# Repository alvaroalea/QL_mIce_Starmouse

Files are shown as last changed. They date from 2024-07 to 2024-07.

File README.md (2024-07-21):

# QL_mIce_Starmouse
Mouse Interface for sinclair QL, mIce and Starmouse compatible

Reverse Engineered and adapted in 2024 by Alvaro Alea Fernandez

License under: CERN Open Hardware Licence Version 2 - Strongly Reciprocal

https://ohwr.org/cern_ohl_s_v2.txt

My work is only copy the design to Kicad, all (C) are retaing to the original owners.

# Introduction

ICE was a early graphic enviroment for the Sinclair QL, it was distributed in ROM Cartridge format, version 1 use keys, but version 2 incorporate a mouse for manage the enviroment.

This project clone the hardware board that have a socket for a ROM chip with ICE, and the circuit to manage te mouse, This Board has been design to match 1:1 the pictures I found of the original board, so can schematic and board can be usefull to repair the original Cartridge.

Original use a bus-mouse, a early kind of no-smart mouse where the signal of the encoders in X and Y are passed to the host computer, this kind of mouse area also used by BBC, Spectrum, Comodore Amiga, Atari ST and early PC XT, today is almost imposible to got one, so I add a second board, using a raspberry pi pico microcontroller that emulate this kind of mouses with a standard USB mouse. This board can also be used on other computers with the adecuate wiring.

A Spanish Company develop another mouse interface for the QL, Starmouse, this interface emulate key push using the second Joystick port (that is also used for the F1-F5 keys) and got power from the cartridge port. This second board can also allow to emulate this mouse. if you connect the adecuate cable to the joystick port.

A small switch in the board will allow you to select, even on they fly, which mouse emulate.

in the folder case there is a PDF with a sticker and a 3D model to print a case for this interface.

in the folder pizero_mouse_usb you can found the source code and binery (.UF2 file) of the firmware to install on the raspberry pi pico. you should use a "waveshare RP-2024 Zero"

in the folder gerber_to_order you can found .zip files ready to send to the mains PCB manufacturers (this is automatic generated, not checked, you should do by yourself)

# Technical Information

This kind of mouse are not the best option for a moderm, multikasking operating system, there is no driver for the mouses, and the programs itself has to take care of pooling the device constantely to got the movement, for the Ice enviroment the vendor provide a toolkit (library) of routines to make easy the integration, but AFAIK, there where no aditional sofware that allow to use it. In the case of the Starmouse, there is only one program that use it, and there is no companion toolkit to use it.

There is no pointer enviroment driver for neither of the mouses.

# Pictures

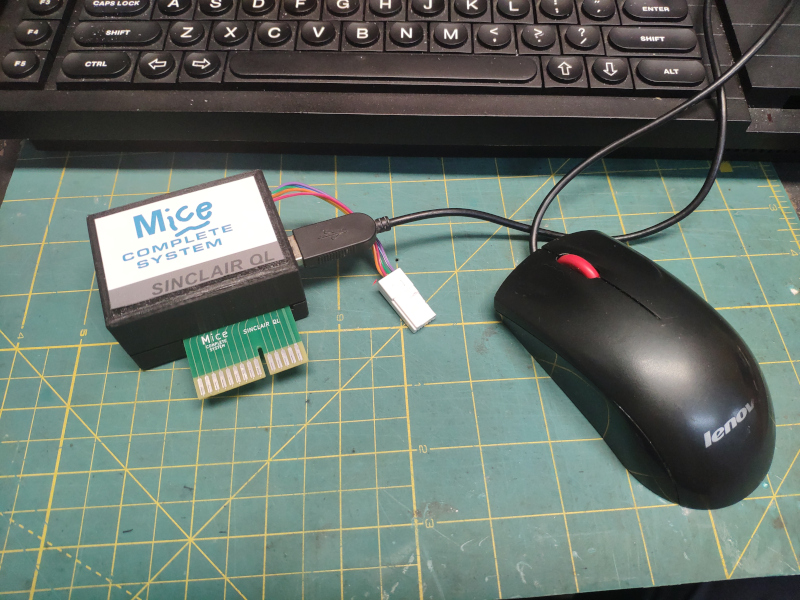
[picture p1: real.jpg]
Real


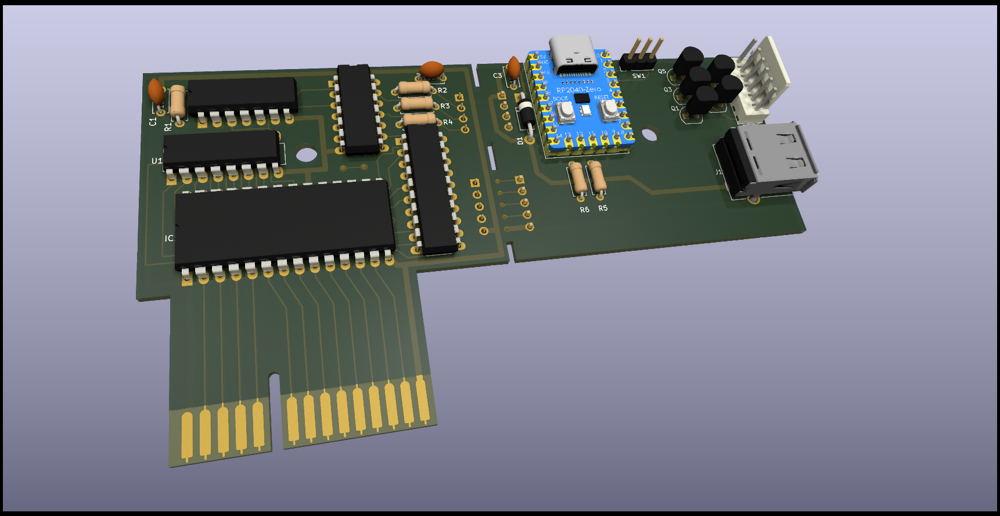
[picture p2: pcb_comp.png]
PCB Componentes Side


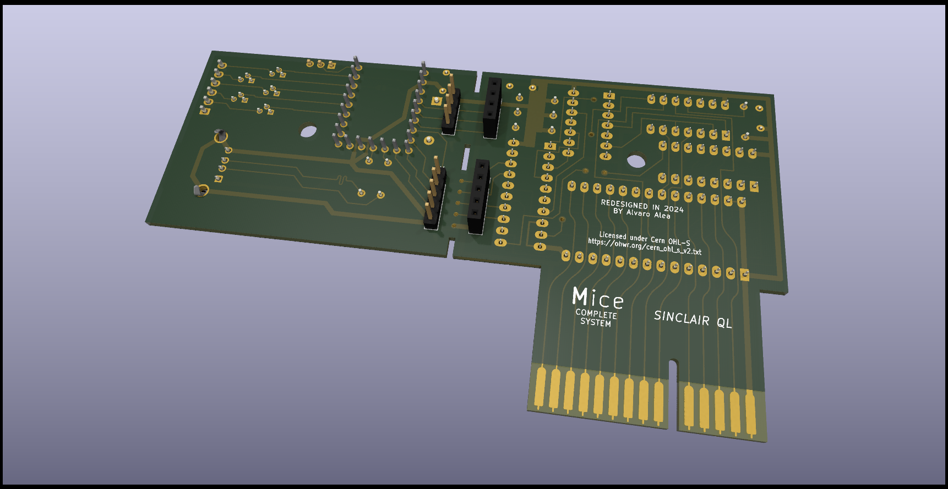
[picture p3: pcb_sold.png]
PCB Solder Side


# Links

https://qlwiki.qlforum.co.uk/doku.php?id=qlwiki:ice

https://qlwiki.qlforum.co.uk/doku.php?id=qlwiki:starmouse

https://sinclairql.speccy.org/articulos/historia/starmouse.htm

https://sinclairql.speccy.org/articulos/hardware/escarabajo.htm

https://www.waveshare.com/rp2040-zero.htm

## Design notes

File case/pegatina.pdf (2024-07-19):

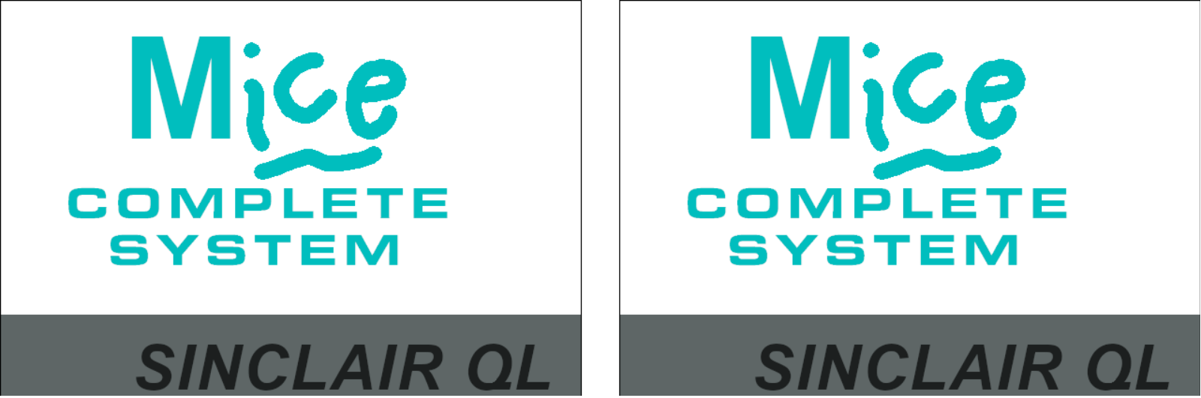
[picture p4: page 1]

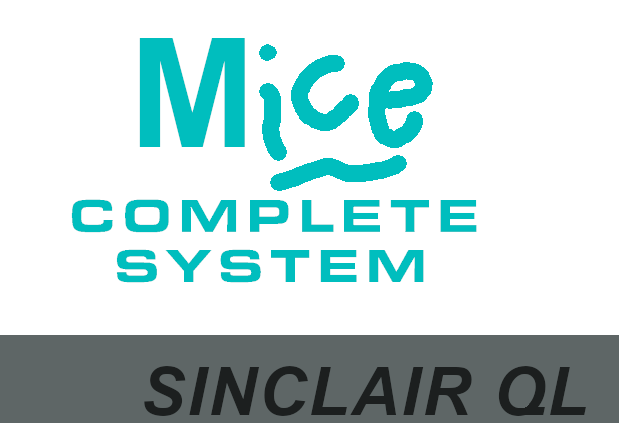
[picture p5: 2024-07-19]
case/pegatina.png

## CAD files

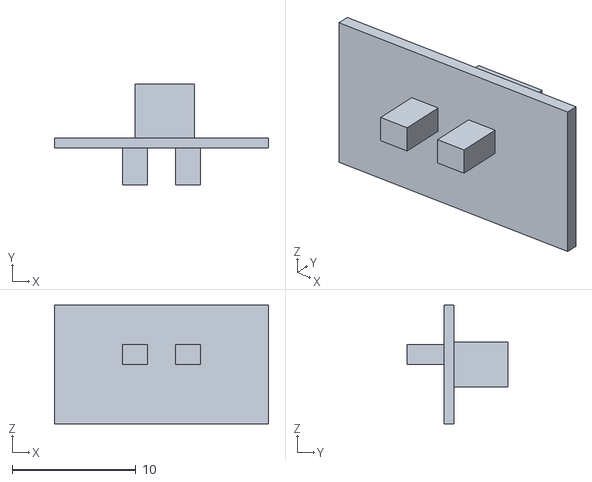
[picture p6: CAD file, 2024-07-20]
case/mice_3_case-switch.stl
17.3 x 8.20 x 9.60

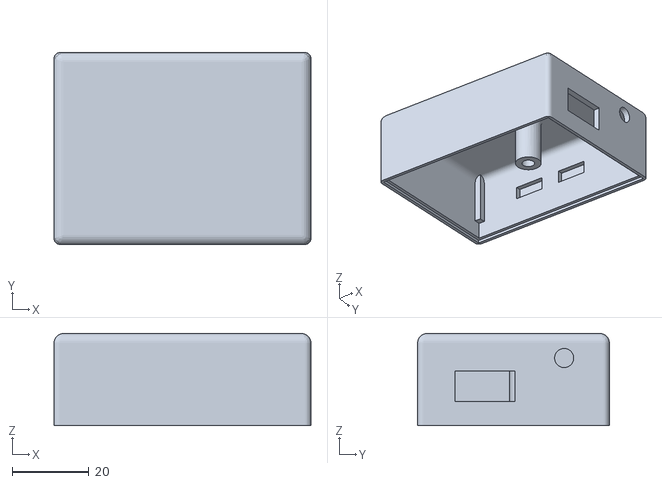
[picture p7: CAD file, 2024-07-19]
case/mice_3_case-superior.stl
67.0 x 50.0 x 24.0

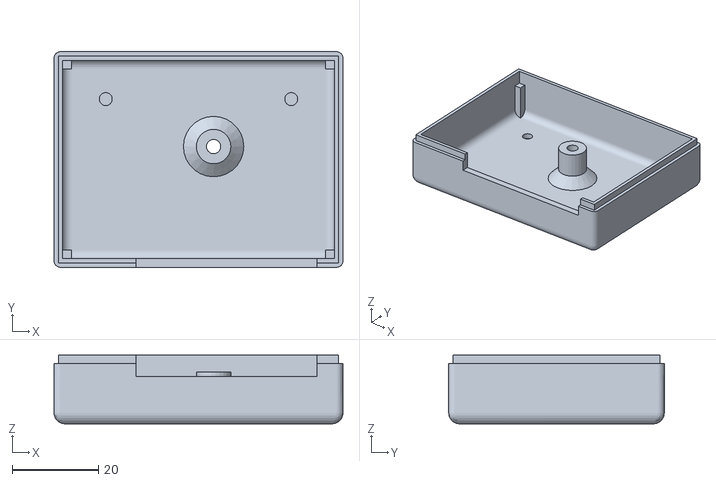
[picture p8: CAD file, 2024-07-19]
case/mice_3_case-inferior.stl
67.0 x 50.0 x 15.9

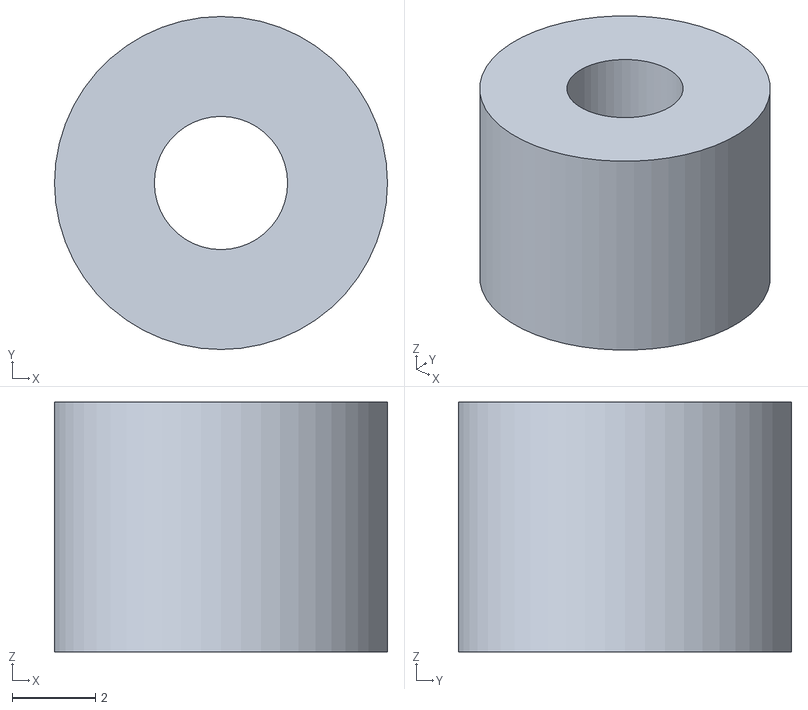
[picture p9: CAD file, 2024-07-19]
case/mice_3_case-separador.stl
8.00 x 8.00 x 6.00

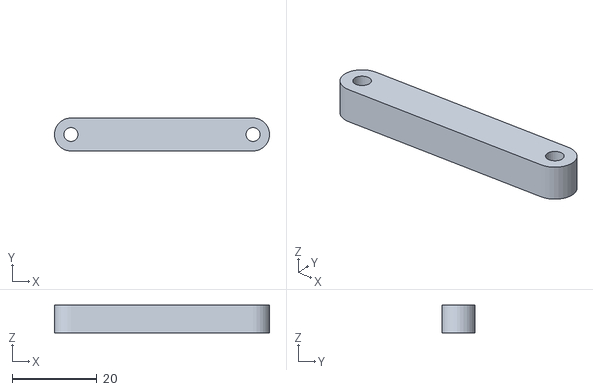
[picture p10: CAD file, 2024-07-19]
case/mice_3_case-pie.stl
50.8 x 7.80 x 6.50

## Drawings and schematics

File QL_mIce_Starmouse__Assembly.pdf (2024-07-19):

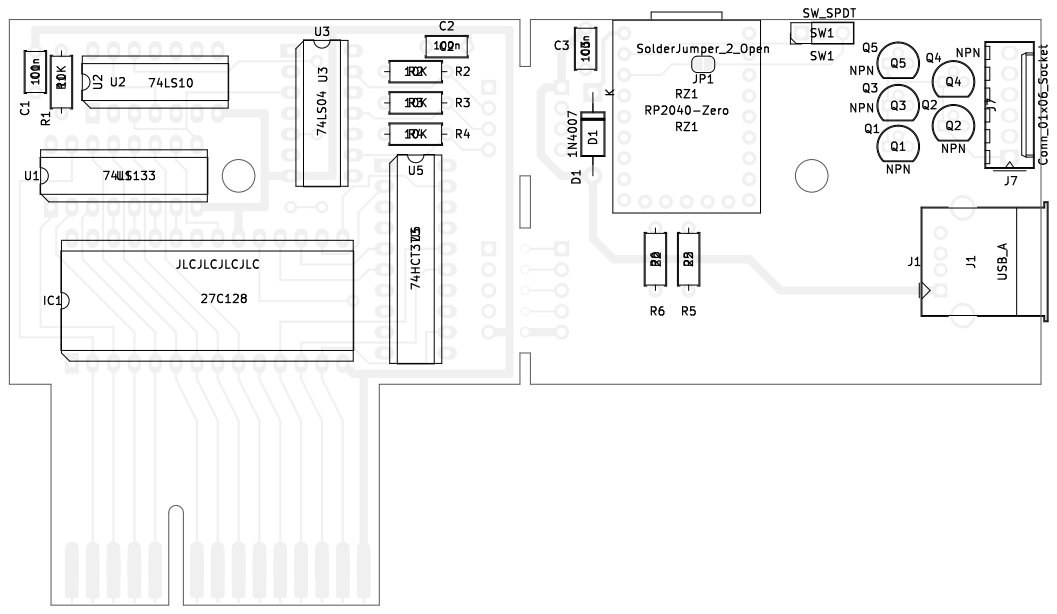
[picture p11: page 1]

Id: 1/1 Title: 16Kb ROM Cartridge for Sinclair QL

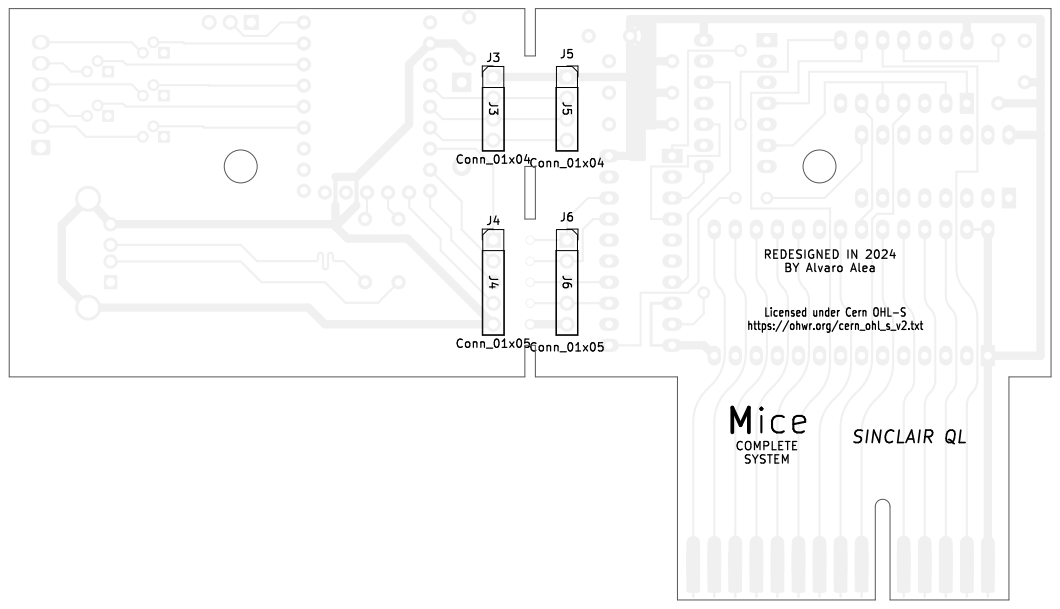
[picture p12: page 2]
Mice; Licensed; under Cern; OHL-S; https://ohwr.org/cern_ohl_s_v2.txt SINCLAIR; REDESIGNED; Alvaro; Alea COMPLETE; SYSTEM; D Date: 2024-07-19 KiCad; E.D.A. 8.0.3 Size: A4; Rev: 0; File: QL_mIce_Starmouse.kicad_pcb Sheet: (C) 2022 Alvaro Alea; Fdz.; IC2 should; https://ohwr.org/cern_ohl_s_v2.txt CERN; Open; Hardware; Licence Version 2 - Strongly; Reciprocal Under license; Conn_01x05 J6 Conn_01x04 J3 Conn_01x05 J4; Conn_01x04 J5

Id: 1/1 Title: 16Kb ROM Cartridge for Sinclair QL

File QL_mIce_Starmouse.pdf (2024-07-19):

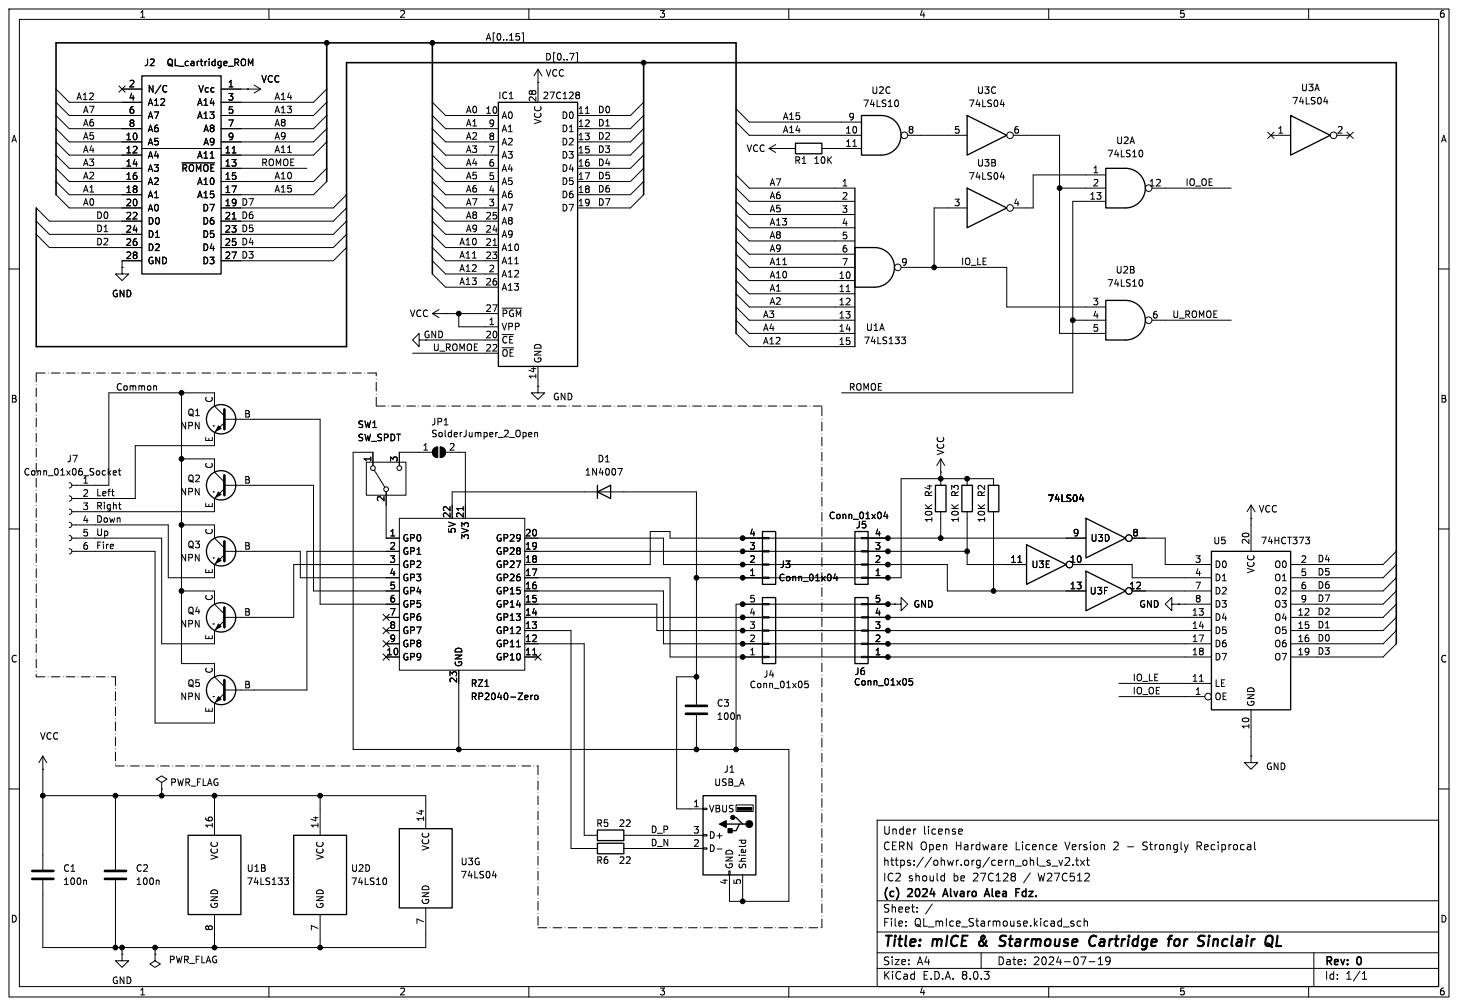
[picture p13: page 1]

Id: 1/1 Title: mICE & Starmouse Cartridge for Sinclair QL

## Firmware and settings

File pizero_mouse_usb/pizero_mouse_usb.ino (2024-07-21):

/*********************************************************************
 Adafruit invests time and resources providing this open source code,
 please support Adafruit and open-source hardware by purchasing
 products from Adafruit!

 MIT license, check LICENSE for more information
 Copyright (c) 2019 Ha Thach for Adafruit Industries
 All text above, and the splash screen below must be included in
 any redistribution
*********************************************************************/

/* This code is based on the example that demonstrates use of both device and host, where
 * - Device run on native usb controller (roothub port0)
 * - Host depending on MCUs run on either:
 *   - rp2040: bit-banging 2 GPIOs with the help of Pico-PIO-USB library (roothub port1)
 *
 * Requirements:
 * - For rp2040:
 *   - [Pico-PIO-USB](https://github.com/sekigon-gonnoc/Pico-PIO-USB) library
 *   - 2 consecutive GPIOs: D+ is defined by PIN_USB_HOST_DP, D- = D+ +1
 *   - Provide VBus (5v) and GND for peripheral
 *   - CPU Speed must be either 120 or 240 Mhz. Selected via "Menu -> CPU Speed"
 */

/* 
THIS CODE IS ALSO BASED ON:

     RP2040 - USB to quadrature mouse converter
    Copyright (C) 2023 Darren Jones
    Copyright (C) 2017-2020 Simon Inns

  This file is part of RP2040 Mouse based on the original SmallyMouse from Simon Inns.

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
    You should have received a copy of the GNU General Public License
    along with this program.  If not, see <http://www.gnu.org/licenses/>.
*/

/*
 * Compile it on arduino using this toolchain: https://github.com/earlephilhower/arduino-pico
 * Library Used: Adafruit TinyUSB Library, Pico PIO USB, RPI_PICO_Timerinterrupt
 *
 * WARNING! Pico Pio USB shall be version 0.5.3, version 0.6.0 has a bug and is not working.
 *
 * config in Tools-> CPU Speed: 120Mhz
 *           Tools-> USB Stack: Adafruit TinyUSB
 */

// pio-usb is required for rp2040 host
#define HOST_PIN_DP   11   // Pin used as D+ for host, D- = D+ + 1
#include "pio_usb.h"

#include "Adafruit_TinyUSB.h"
// USB Host object
Adafruit_USBH_Host USBHost;
// holding device descriptor
tusb_desc_device_t desc_device;

//#include <Adafruit_NeoPixel.h>

volatile int8_t mouseDirectionX = 0;    // X direction (0 = decrement, 1 = increment)
volatile int8_t mouseEncoderPhaseX = 0; // X Quadrature phase (0-3)

volatile int8_t mouseDirectionY = 0;    // Y direction (0 = decrement, 1 = increment)
volatile int8_t mouseEncoderPhaseY = 0; // Y Quadrature phase (0-3)

volatile int16_t mouseDistanceX = 0; // Distance left for mouse to move
volatile int16_t mouseDistanceY = 0; // Distance left for mouse to move

#define XA_PIN 13
#define XB_PIN 26
#define YA_PIN 15
#define YB_PIN 14
#define LMB_PIN 27
#define RMB_PIN 28
#define CMB_PIN 29
#define JOY_F_PIN 1
#define JOY_U_PIN 2
#define JOY_D_PIN 3
#define JOY_R_PIN 4
#define JOY_L_PIN 5
#define SWITCH_PIN 0
#define NEOPIXEL 16

//Adafruit_NeoPixel pixels(1, NEOPIXEL, NEO_GRB + NEO_KHZ800);

static bool config=0;

// Can be included as many times as necessary, without `Multiple Definitions` Linker Error
#include "RPi_Pico_TimerInterrupt.h"

// To be included only in main(), .ino with setup() to avoid `Multiple Definitions` Linker Error
#include "RPi_Pico_ISR_Timer.h"
#define TIMER_INTERVAL_MS 1L
// Init RPI_PICO_Timer
RPI_PICO_Timer ITimer1(1);
RPI_PICO_ISR_Timer ISR_timer;

struct repeating_timer timer1;



bool timer1_callback(struct repeating_timer *t)
{
  // Silence compilation warning
  (void)t;
  if (config) {
    // Process X output
    if (mouseDistanceX != 0) {
      if (mouseDistanceX > 0) {
        mouseDistanceX--;
        Serial.println("X- mov");
        mouseEncoderPhaseX++;
        if (mouseEncoderPhaseX > 3) mouseEncoderPhaseX = 0;
      } else if (mouseDistanceX < 0) {
        mouseDistanceX++;
        Serial.println("X+ mov");
        mouseEncoderPhaseX--;
        if (mouseEncoderPhaseX < 0) mouseEncoderPhaseX = 3;
      }
      // Set the output pins according to the current phase
      if (mouseEncoderPhaseX == 0) digitalWrite(XA_PIN, 1); // Set X1 to 1
      if (mouseEncoderPhaseX == 1) digitalWrite(XB_PIN, 1); // Set X2 to 1
      if (mouseEncoderPhaseX == 2) digitalWrite(XA_PIN, 0); // Set X1 to 0
      if (mouseEncoderPhaseX == 3) digitalWrite(XB_PIN, 0); // Set X2 to 0
    }
    // Process Y output
    if (mouseDistanceY != 0) {
      if (mouseDistanceY > 0) {
        mouseDistanceY--;
        Serial.println("Y- mov");
        mouseEncoderPhaseY++;
        if (mouseEncoderPhaseY > 3) mouseEncoderPhaseY = 0;
      } else if (mouseDistanceY < 0) {
        mouseDistanceY++;
        Serial.println("Y+ mov");
        mouseEncoderPhaseY--;
        if (mouseEncoderPhaseY < 0) mouseEncoderPhaseY = 3;
      }
      // Set the output pins according to the current phase
      if (mouseEncoderPhaseY == 0) digitalWrite(YA_PIN, 1); // Set Y1 to 1
      if (mouseEncoderPhaseY == 1) digitalWrite(YB_PIN, 1); // Set Y2 to 1
      if (mouseEncoderPhaseY == 2) digitalWrite(YA_PIN, 0); // Set Y1 to 0
      if (mouseEncoderPhaseY == 3) digitalWrite(YB_PIN, 0); // Set Y2 to 0
    }
  } else {
    if (mouseDistanceX > 0) {
      mouseDistanceX--;
      digitalWrite(JOY_L_PIN,0); // left
      digitalWrite(JOY_R_PIN,1); // right
    } else if (mouseDistanceX < 0) {
      mouseDistanceX++;
      digitalWrite(JOY_L_PIN,1); // left
      digitalWrite(JOY_R_PIN,0); // right
    } else {
      digitalWrite(JOY_L_PIN,0); // left
      digitalWrite(JOY_R_PIN,0); // right
    }
    if (mouseDistanceY > 0) {
      mouseDistanceY--;
      digitalWrite(JOY_U_PIN,0); // left
      digitalWrite(JOY_D_PIN,1); // right
    } else if (mouseDistanceY < 0) {
      mouseDistanceY++;
      digitalWrite(JOY_U_PIN,1); // left
      digitalWrite(JOY_D_PIN,0); // right
    } else {
      digitalWrite(JOY_U_PIN,0); // left
      digitalWrite(JOY_D_PIN,0); // right
    }
  }
  return true;
}

//------------- Core0 -------------//

void setup() {
  //mice buttons
  pinMode(LMB_PIN, OUTPUT);
  pinMode(RMB_PIN, OUTPUT);
  pinMode(CMB_PIN, OUTPUT);
  digitalWrite(LMB_PIN,1);//left button, buttons are inverted
  digitalWrite(RMB_PIN,1); //right button
  digitalWrite(CMB_PIN,1);//central button

  //mice xy
  pinMode(XA_PIN, OUTPUT);
  pinMode(XB_PIN, OUTPUT);
  pinMode(YA_PIN, OUTPUT);
  pinMode(YB_PIN, OUTPUT);
  //joystick output
  pinMode(JOY_L_PIN, OUTPUT);
  pinMode(JOY_R_PIN, OUTPUT);
  pinMode(JOY_D_PIN, OUTPUT);
  pinMode(JOY_U_PIN, OUTPUT);
  pinMode(JOY_F_PIN, OUTPUT);
  digitalWrite(JOY_L_PIN,0);
  digitalWrite(JOY_R_PIN,0);
  digitalWrite(JOY_D_PIN,0);
  digitalWrite(JOY_U_PIN,0);
  digitalWrite(JOY_F_PIN,0);

  // CFG switch
  pinMode(SWITCH_PIN, INPUT_PULLUP);

  Serial.begin(115200);
  //while ( !Serial ) delay(10);   // wait for native usb
  Serial.println("USB Mouse to BusMouse/Joystick Adapter, (C) A.Alea 2024 V0.2");

  if (ITimer1.attachInterruptInterval(TIMER_INTERVAL_MS * 1000, timer1_callback))
    {
      Serial.print(F("Starting ITimer1 OK, millis() = ")); Serial.println(millis());
    } else {
      Serial.println(F("Can't set ITimer1. Select another freq. or timer"));
    }
  
  //pixels.begin(); // INITIALIZE NeoPixel strip object (REQUIRED)
  //pixels.setPixelColor(0, pixels.Color(128, 0, 0));
  //pixels.show(); 
  Serial.println("Core0 End Setup");


}

void loop() {
  //Serial.printf("0 Es %i\n",digitalRead(0));
  Serial.flush();
  bool oldcfg = config;
  config=digitalRead(SWITCH_PIN);
  if (oldcfg!=config) {
    if (config==0) {
        Serial.println("CONFIG: Joystick Emulation");
        //pixels.setPixelColor(0, pixels.Color(128, 0, 0));
        //pixels.show(); 
    }
    if (config==1) {
        Serial.println("CONFIG: mICE Mouse");
        digitalWrite(JOY_L_PIN,0);
        digitalWrite(JOY_R_PIN,0);
        digitalWrite(JOY_D_PIN,0);
        digitalWrite(JOY_U_PIN,0);
        digitalWrite(JOY_F_PIN,0);
        //pixels.setPixelColor(0, pixels.Color(0, 128, 0));
        //pixels.show(); 
    }
  }
}

//------------- Core1 -------------//

void setup1() {
  //while ( !Serial ) delay(10);   // wait for native usb
  Serial.println("Core1 setup to run TinyUSB host with pio-usb");

  // Check for CPU frequency, must be multiple of 120Mhz for bit-banging USB
  uint32_t cpu_hz = clock_get_hz(clk_sys);
  if ( cpu_hz != 120000000UL && cpu_hz != 240000000UL ) {
    while ( !Serial ) delay(10);   // wait for native usb
    Serial.printf("Error: CPU Clock = %u, PIO USB require CPU clock must be multiple of 120 Mhz\r\n", cpu_hz);
    Serial.printf("Change your CPU Clock to either 120 or 240 Mhz in Menu->CPU Speed \r\n", cpu_hz);
    while(1) delay(1);
  }

  pio_usb_configuration_t pio_cfg = PIO_USB_DEFAULT_CONFIG;
  pio_cfg.pin_dp = HOST_PIN_DP;
 
 #if defined(ARDUINO_RASPBERRY_PI_PICO_W)
  /* https://github.com/sekigon-gonnoc/Pico-PIO-USB/issues/46 */
  pio_cfg.sm_tx      = 3;
  pio_cfg.sm_rx      = 2;
  pio_cfg.sm_eop     = 3;
  pio_cfg.pio_rx_num = 0;
  pio_cfg.pio_tx_num = 1;
  pio_cfg.tx_ch      = 9;
 #endif /* ARDUINO_RASPBERRY_PI_PICO_W */
 
  USBHost.configure_pio_usb(1, &pio_cfg);

  // run host stack on controller (rhport) 1
  // Note: For rp2040 pico-pio-usb, calling USBHost.begin() on core1 will have most of the
  // host bit-banging processing works done in core1 to free up core0 for other works
  USBHost.begin(1);
}

void loop1() {
  USBHost.task();
}

//--------------------------------------------------------------------+
// Host HID
//--------------------------------------------------------------------+

// Invoked when device with hid interface is mounted
// Report descriptor is also available for use. tuh_hid_parse_report_descriptor()
// can be used to parse common/simple enough descriptor.
// Note: if report descriptor length > CFG_TUH_ENUMERATION_BUFSIZE, it will be skipped
// therefore report_desc = NULL, desc_len = 0
void tuh_hid_mount_cb(uint8_t dev_addr, uint8_t instance, uint8_t const* desc_report, uint16_t desc_len)
{
  (void)desc_report;
  (void)desc_len;

  // Interface protocol (hid_interface_protocol_enum_t)
  const char* protocol_str[] = { "None", "Keyboard", "Mouse" };
  uint8_t const itf_protocol = tuh_hid_interface_protocol(dev_addr, instance);

  uint16_t vid, pid;
  tuh_vid_pid_get(dev_addr, &vid, &pid);

  Serial.printf( "[%04x:%04x][%u] HID Interface%u, Protocol = %s\r\n", vid, pid, dev_addr, instance, protocol_str[itf_protocol]);

  // Receive report from mouse only
  // tuh_hid_report_received_cb() will be invoked when report is available
  if (itf_protocol == HID_ITF_PROTOCOL_MOUSE)
  {
    if ( !tuh_hid_receive_report(dev_addr, instance) )
    {
      Serial.printf("Error: cannot request report\r\n");
    }
  }
}

// Invoked when device with hid interface is un-mounted
void tuh_hid_umount_cb(uint8_t dev_addr, uint8_t instance)
{
 Serial.printf("[%u] HID Interface%u is unmounted\r\n", dev_addr, instance);
}

static void process_mouse_report(uint8_t dev_addr, hid_mouse_report_t const * report)
{
  char l = report->buttons & MOUSE_BUTTON_LEFT   ? 'L' : '-';
  char m = report->buttons & MOUSE_BUTTON_MIDDLE ? 'M' : '-';
  char r = report->buttons & MOUSE_BUTTON_RIGHT  ? 'R' : '-';
  Serial.printf( "[%u] %c%c%c %d %d %d\r\n", dev_addr, l, m, r, report->x, report->y, report->wheel);
  
  mouseDistanceX += report->x;
  mouseDistanceY += report->y;
  if (config){ //mice
    digitalWrite(LMB_PIN,(report->buttons & MOUSE_BUTTON_LEFT  ) ? 0:1);//left button
    digitalWrite(RMB_PIN,(report->buttons & MOUSE_BUTTON_RIGHT ) ? 0:1);//right button
    digitalWrite(CMB_PIN,(report->buttons & MOUSE_BUTTON_MIDDLE) ? 0:1);//central button
  } else { //joystick or 1 button mouse
    digitalWrite(JOY_F_PIN,(report->buttons & (MOUSE_BUTTON_RIGHT|MOUSE_BUTTON_MIDDLE|MOUSE_BUTTON_LEFT)) ? 1:0); // Any button
  }
}

// Invoked when received report from device via interrupt endpoint
void tuh_hid_report_received_cb(uint8_t dev_addr, uint8_t instance, uint8_t const* report, uint16_t len)
{
  (void) len;
  uint8_t const itf_protocol = tuh_hid_interface_protocol(dev_addr, instance);

  switch(itf_protocol)
  {
    case HID_ITF_PROTOCOL_MOUSE:
      process_mouse_report(dev_addr, (hid_mouse_report_t const*) report );
    break;

    default: break;
  }

  // continue to request to receive report
  if ( !tuh_hid_receive_report(dev_addr, instance) )
  {
    Serial.printf("Error: cannot request report\r\n");
  }
}

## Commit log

2024-07-20 fix case switch
    [mice_3_case-switch.stl]
2024-07-26 deleted old files
    [MICE_3.GBL, MICE_3.GBO, MICE_3.GBS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]
2024-08-13 fix pizero foot-print to allow easy unsolder
    [QL_mIce_Starmouse-B_Cu.gbr, QL_mIce_Starmouse-B_Mask.gbr, QL_mIce_Starmouse-B_Silks.gbr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]

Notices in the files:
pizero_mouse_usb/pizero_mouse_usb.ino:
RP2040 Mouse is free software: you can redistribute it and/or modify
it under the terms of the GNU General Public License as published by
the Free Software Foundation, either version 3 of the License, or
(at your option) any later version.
